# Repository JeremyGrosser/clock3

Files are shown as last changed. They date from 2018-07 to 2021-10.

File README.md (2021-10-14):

This repository contains firmware for my 3 time zone clock based on the [Adafruit Feather M0 Wifi](https://www.adafruit.com/product/3010). This project is very incomplete and is unlikely to be reproducible with the code listed here.

Some of the software components (eg. samd21 drivers) may be useful to others, so I'm making this repository public, but have no intention to maintain it long term.

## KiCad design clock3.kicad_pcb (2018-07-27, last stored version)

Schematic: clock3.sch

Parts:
BAT1: BS-7; Battery_Holder_Coin_2032_BS-7; MPN BS-7; Digi-Key_PN BS-7-ND
BOOT1, BOOT2: EG1218; Switch_Slide_11.6x4mm_EG1218; MPN EG1218; Digi-Key_PN EG1903-ND
C1, C2, C9: 4.7uF; C_0603_1608Metric
C3: 10uF; C_0805_2012Metric
C4, C5: 16pF; C_0603_1608Metric
C6, C7, C8, C12, C13, C14, C15: 100nF; C_0603_1608Metric
C10: 10nF; C_0603_1608Metric
C11: 1uF; C_0603_1608Metric
C17, C18: 5pF; C_0603_1608Metric
D1, D2, D3, D4: LED; LED_1206_3216Metric
J1: 10118194-0001LF; USB_Micro_B_Female_10118194-0001LF; MPN 10118194-0001LF; Digi-Key_PN 609-4618-1-ND
J2: SWD; Molex_KK-254_AE-6410-06A_1x06_P2.54mm_Vertical
J3, J4, J5: Conn_01x06_Male; Molex_KK-254_AE-6410-06A_1x06_P2.54mm_Vertical
MK1, MK2, MK3, MK4: Mounting_Hole_PAD; MountingHole_2.2mm_M2_DIN965_Pad
R2, R3: 10k; R_0603_1608Metric
R4, R5, R6, R7: R; R_0603_1608Metric
S1, S2, S3, S4: B3F-3150
U1: AP2114H-3_3TRG1; SOT-223; MPN AP2114H-3.3TRG1; Digi-Key_PN AP2114H-3.3TRG1DICT-ND
U2: STM32F102CBTx; LQFP-48_7x7mm_P0.5mm
Y1: 8MHz 18pF 30ppm; Crystal_SMD_HC49-US_AT49
Y2: 32.768kHz 12.5pF 20ppm; Crystal_SMD_SeikoEpson_MC146-4Pin_6.7x1.5mm

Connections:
/BOOT0: R2.2, U2.44 (BOOT0)
/BOOT1: R3.2, U2.20 (PB2)
/BUTTON1: C12.2, S1.1, U2.28 (PB15)
/BUTTON2: C13.2, S2.1, U2.27 (PB14)
/BUTTON3: C14.2, S3.1, U2.26 (PB13)
/I2C1_SCL: J3.4, J4.4, J5.4, U2.42 (PB6)
/I2C1_SDA: J3.3, J4.3, J5.3, U2.43 (PB7)
/LED1: D1.1, U2.10 (PA0)
/LED2: D2.1, U2.11 (PA1)
/LED3: D3.1, U2.29 (PA8)
/SWCLK: J2.2, U2.37 (PA14)
/SWDIO: J2.4, U2.34 (PA13)
/SWO: J2.6, U2.39 (PB3)
/USB_D+: J1.3, U2.33 (PA12)
/USB_D-: J1.2, U2.32 (PA11)
/VBAT: BAT1.Pos, U2.1 (VBAT)
/~RESET: C15.2, J2.5, S4.1, U2.7 (NRST)
GND: BAT1.Neg, BOOT1.3, BOOT2.3, C1.2, C2.2, C3.2, C4.2, C5.2, C6.2, C7.2, C8.2, C9.2, C10.2, C11.2, C12.1, C13.1, C14.1, C15.1, C17.2, C18.2, J1.4, J1.5, J1.SH, J2.3, J3.2, J3.6, J4.2, J4.6, J5.2, J5.6, MK1.1, MK2.1, MK3.1, MK4.1, S1.2, S1.3, S1.4, S2.2, S2.3, S2.4, S3.2, S3.3, S3.4, S4.2, S4.3, S4.4, U1.1, U2.8 (VSSA), U2.23 (VSS), U2.35 (VSS), U2.47 (VSS)
unnamed: BOOT1.2, R2.1
unnamed: BOOT2.2, R3.1
unnamed: C4.1, U2.5 (PD0), Y1.2
unnamed: C5.1, U2.6 (PD1), Y1.1
unnamed: C17.1, U2.3 (PC14), Y2.2
unnamed: C18.1, U2.4 (PC15), Y2.1
unnamed: D1.2, R4.2
unnamed: D2.2, R5.2
unnamed: D3.2, R6.2
unnamed: D4.2, R7.2
VCC: C1.1, J1.1, J3.1, J4.1, J5.1, U1.3
VDD: BOOT1.1, BOOT2.1, C2.1, C3.1, C6.1, C7.1, C8.1, C9.1, C10.1, C11.1, J2.1, J3.5, J4.5, J5.5, R4.1, R5.1, R6.1, R7.1, U1.2, U1.4, U2.9 (VDDA), U2.24 (VDD), U2.36 (VDD), U2.48 (VDD)

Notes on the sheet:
POWER 5V IN 3.3V @ 1A OUT
DEBUG
LED DISPLAYS
USB
BUTTONS AND SWITCHES
WIFI
LEDS
VDD3
VDDA

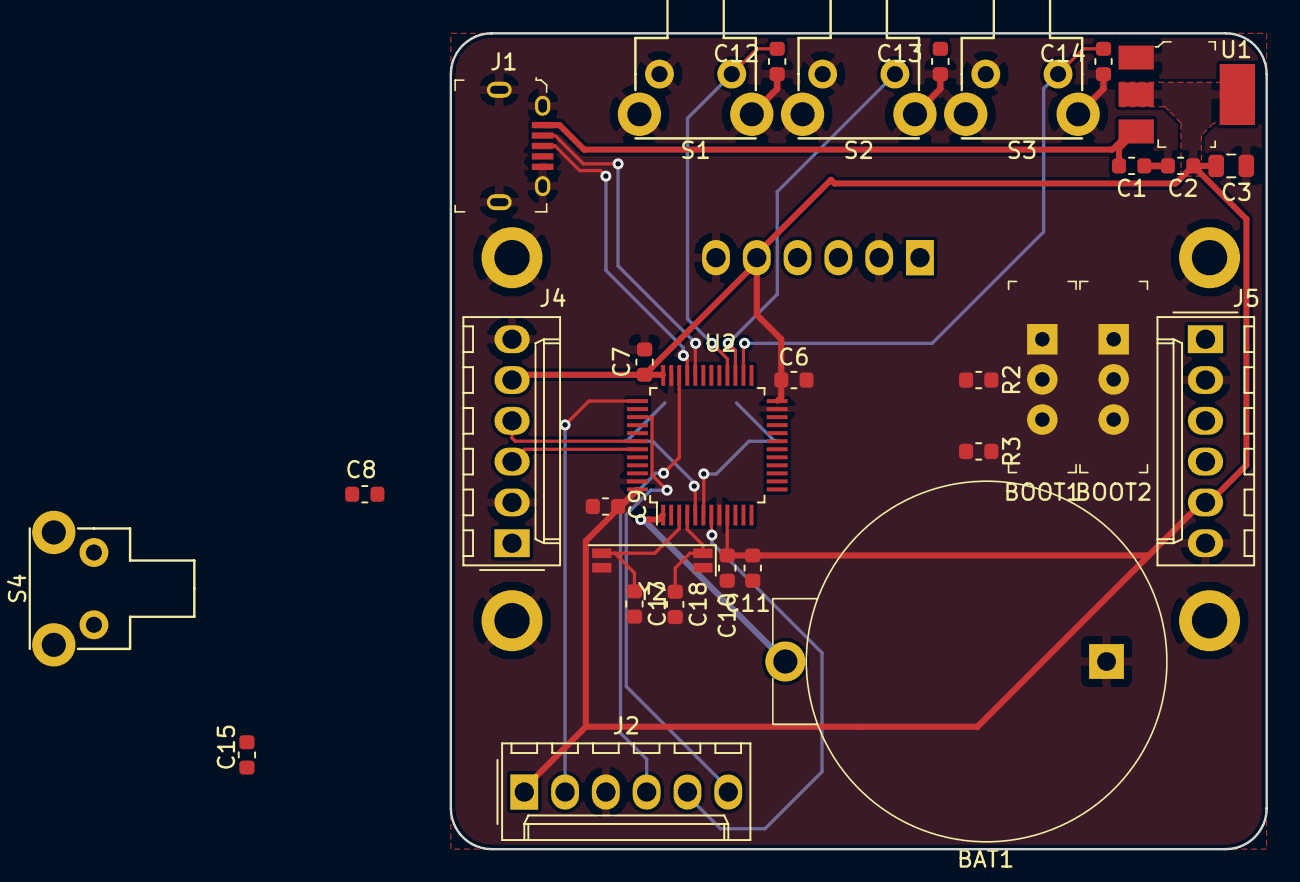
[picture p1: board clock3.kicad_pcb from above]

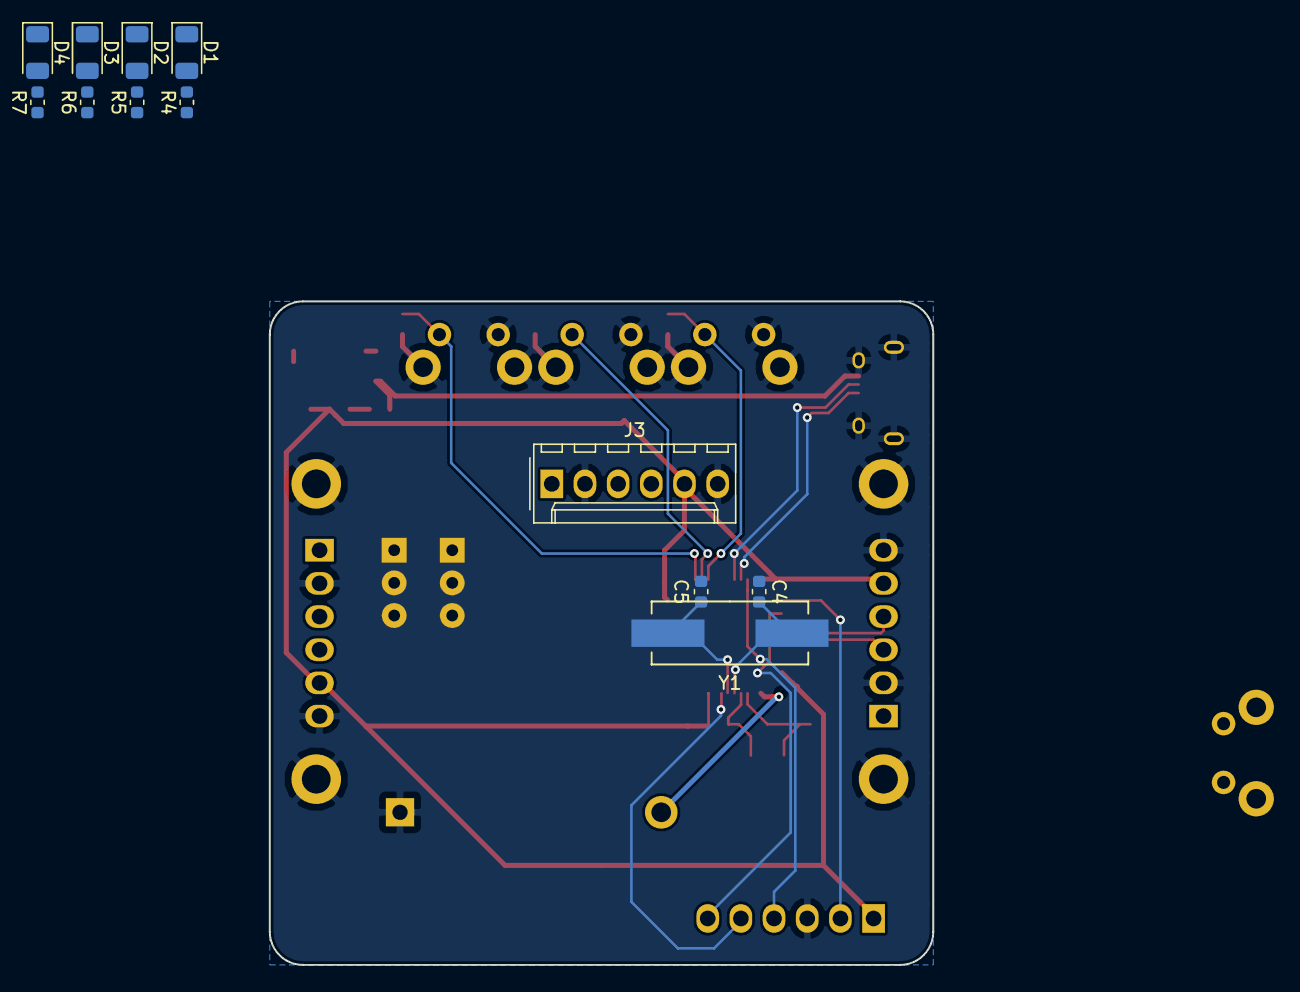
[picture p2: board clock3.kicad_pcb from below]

Board: 2 copper layers, 50.8 x 50.8 mm, 47 parts (12 on the bottom side), 30 nets.

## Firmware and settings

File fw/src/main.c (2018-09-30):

#include <platform/gpio.h>
#include <platform/i2c.h>
#include <platform/rtc.h>
#include <platform.h>
#include <board.h>

#include <stdint.h>
#include <stdio.h>
#include <string.h>

#include <sys/time.h>
#include <errno.h>

#include <driver/ht16k33/ht16k33.h>
#include <driver/atw/atw.h>

#define WIFI_SSID "sierra24"
#define WIFI_PSK "whatevenisapassword"

#define CONSOLE_MAXLEN 128
uint8_t console_buf[CONSOLE_MAXLEN] = {0};
uint8_t *console_ptr = console_buf;
size_t console_avail = CONSOLE_MAXLEN;

void process_command(uint8_t *line, size_t len) {
	printf("command[%d]: %s\r\n", len, line);
}

static void console_loop(void) {
	uint8_t *eol;
	int err;

	err = console_read(console_ptr, console_avail);
	if(err <= 0) {
		return;
	}

	console_ptr += err;
	console_avail -= err;

	eol = (uint8_t *)memchr(console_buf, '\n', CONSOLE_MAXLEN);
	if(eol != NULL) {
		process_command(console_buf, (eol - console_buf));
		memset(console_buf, 0x00, CONSOLE_MAXLEN);
		console_ptr = console_buf;
		console_avail = CONSOLE_MAXLEN;
	}else if(console_avail == 0) {
		printf("console buffer overflow!\r\n\r\n");
		memset(console_buf, 0x00, CONSOLE_MAXLEN);
		console_ptr = console_buf;
		console_avail = CONSOLE_MAXLEN;
	}
}

void button0_interrupt(void) {
	struct tm *now;

	now = rtc_read();
	now->tm_min = ((now->tm_min + 1) % 60);
	now->tm_sec = 0;
	rtc_write(now);
}

void button1_interrupt(void) {
	struct tm *now;

	now = rtc_read();
	now->tm_hour = ((now->tm_hour + 1) % 24);
	rtc_write(now);
}

void display_time(ht16k33_t *display, struct tm *now) {
	if(now->tm_hour > 0) {
		ht16k33_set(display, ht16k33_column[0], ht16k33_digit[now->tm_hour / 10]);
		ht16k33_set(display, ht16k33_column[1], ht16k33_digit[now->tm_hour % 10]);
	}else{
		ht16k33_set(display, ht16k33_column[0], ht16k33_digit[0]);
		ht16k33_set(display, ht16k33_column[1], ht16k33_digit[0]);
	}

	if(now->tm_min > 0) {
		ht16k33_set(display, ht16k33_column[2], ht16k33_digit[now->tm_min / 10]);
		ht16k33_set(display, ht16k33_column[3], ht16k33_digit[now->tm_min % 10]);
	}else{
		ht16k33_set(display, ht16k33_column[2], ht16k33_digit[0]);
		ht16k33_set(display, ht16k33_column[3], ht16k33_digit[0]);
	}
	ht16k33_set(display, ht16k33_column[4], ht16k33_colon);

	ht16k33_flush(display);
}

int main(void) {
	ht16k33_t display[3];
	struct tm *now;
	time_t epoch;
	struct timeval tv;
	int err;

	err = board_init();
	if(err != 0) {
		printf("board_init err=%d\r\n", err);
	}

	/*
	err = atw_connect_wpa(&wifi, (uint8_t *)WIFI_SSID, strlen(WIFI_SSID), (uint8_t *)WIFI_PSK, strlen(WIFI_PSK));
	if(err != 0) {
		printf("atw_connect_wpa failed\r\n");
	}
	*/

	display[0].i2c = &DISPLAY_I2C;
	display[0].i2c_addr = 0x70;
	display[0].brightness = 8;

	display[1].i2c = &DISPLAY_I2C;
	display[1].i2c_addr = 0x73;
	display[1].brightness = 8;

	display[2].i2c = &DISPLAY_I2C;
	display[2].i2c_addr = 0x71;
	display[2].brightness = 8;

	err = ht16k33_setup(&display[0]);
	if(err != 0) {
		printf("display 0 setup failed\r\n");
	}
	err = ht16k33_setup(&display[1]);
	if(err != 0) {
		printf("display 1 setup failed\r\n");
	}
	err = ht16k33_setup(&display[2]);
	if(err != 0) {
		printf("display 2 setup failed\r\n");
	}

	gpio_write(&STATUS_LED, LED_OFF);

	while(1) {
		err = gettimeofday(&tv, NULL);
		if(err != 0) {
			printf("gettimeofday failed: %s\r\n", strerror(errno));
		}else{
			epoch = tv.tv_sec + (3600 * -7);
			now = gmtime(&epoch);
			display_time(&display[0], now);

			epoch = tv.tv_sec + (3600 * -4);
			now = gmtime(&epoch);
			display_time(&display[1], now);

			epoch = tv.tv_sec;
			now = gmtime(&epoch);
			display_time(&display[2], now);
		}

		//atw_handle_events(&wifi);
		console_loop();

		gpio_write(&STATUS_LED, LED_OFF);
		__WFI();
		gpio_write(&STATUS_LED, LED_ON);
	}

	return 0;
}

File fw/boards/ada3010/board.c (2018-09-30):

#include <board.h>
#include <platform.h>
#include <platform/gpio.h>
#include <platform/spi.h>
#include <platform/rtc.h>
#include <platform/i2c.h>
//#include <platform/uart.h>
//#include <driver/atw/atw.h>

#include <stdio.h>

void wifi_interrupt(void) {
	atw_interrupt(&wifi);
}

gpio_t STATUS_LED = {
	.num	= PIN_PA17,
	.config	= {
		.direction	= DIR_OUT,
		.drive		= DRIVE_HIGH,
		.pull		= PULL_ENABLE,
		.pmux		= PMUX_DISABLE,
	},
};

gpio_t BUTTON0 = {
	.num	= PIN_PA02,
	.config	= {
		.direction	= DIR_IN,
		.pull		= PULL_ENABLE,
		.pmux		= PMUX_ENABLE,
		.pmux_function = MUX_PA02A_EIC_EXTINT2,
	},
	.interrupt = {
		.num	= 2,
		.sense	= SENSE_RISE,
		.filter	= FILTER_ENABLE,
		.function = &button0_interrupt,
	},
};

gpio_t BUTTON1 = {
	.num	= PIN_PB08,
	.config	= {
		.direction	= DIR_IN,
		.pull		= PULL_ENABLE,
		.pmux		= PMUX_ENABLE,
		.pmux_function = MUX_PB08A_EIC_EXTINT8,
	},
	.interrupt = {
		.num	= 8,
		.sense	= SENSE_RISE,
		.filter	= FILTER_ENABLE,
		.function = &button1_interrupt,
	},
};

gpio_t ATW_CS = {
	.num	= PIN_PA06,
	.config	= {
		.direction	= DIR_OUT,
		.drive		= DRIVE_LOW,
		.pull		= PULL_ENABLE,
		.pmux		= PMUX_DISABLE,
	},
};

gpio_t ATW_RST = {
	.num	= PIN_PA08,
	.config	= {
		.direction	= DIR_OUT,
		.drive		= DRIVE_LOW,
		.pull		= PULL_ENABLE,
		.pmux		= PMUX_DISABLE,
	},
};

gpio_t ATW_IRQ = {
	.num	= PIN_PA21,
	.config	= {
		.direction		= DIR_IN,
		.drive			= DRIVE_LOW,
		.pull			= PULL_ENABLE,
		.pmux			= PMUX_ENABLE,
		.pmux_function	= MUX_PA21A_EIC_EXTINT5,
	},
	.interrupt = {
		.num	= 5,
		.sense	= SENSE_RISE,
		.filter	= FILTER_DISABLE,
		.function = &wifi_interrupt,
	},
};

gpio_t ATW_MOSI = {
	.num	= PIN_PB10,
	.config = {
		.direction		= DIR_OUT,
		.drive			= DRIVE_LOW,
		.pull			= PULL_ENABLE,
		.pmux			= PMUX_ENABLE,
		.pmux_function	= MUX_PB10D_SERCOM4_PAD2,
	},
};

gpio_t ATW_MISO = {
	.num	= PIN_PA12,
	.config = {
		.direction		= DIR_IN,
		.drive			= DRIVE_LOW,
		.pull			= PULL_DISABLE,
		.pmux			= PMUX_ENABLE,
		.pmux_function	= MUX_PA12D_SERCOM4_PAD0,
	},
};

gpio_t ATW_SCK = {
	.num	= PIN_PB11,
	.config = {
		.direction		= DIR_OUT,
		.drive			= DRIVE_LOW,
		.pull			= PULL_DISABLE,
		.pmux			= PMUX_ENABLE,
		.pmux_function	= MUX_PB11D_SERCOM4_PAD3,
	},
};

gpio_t ATW_CHIP_EN = {
	.num	= PIN_PA14,
	.config = {
		.direction		= DIR_OUT,
		.drive			= DRIVE_HIGH,
		.pull			= PULL_ENABLE,
		.pmux			= PMUX_DISABLE,
	},
};

/*
gpio_t CONSOLE_TXD = {
	.num	= PIN_PA10,
	.config = {
		.direction		= DIR_OUT,
		.drive			= DRIVE_HIGH,
		.pull			= PULL_ENABLE,
		.pmux			= PMUX_ENABLE,
		.pmux_function	= MUX_PA10C_SERCOM0_PAD2,
	},
};

gpio_t CONSOLE_RXD = {
	.num	= PIN_PA11,
	.config = {
		.direction		= DIR_IN,
		.drive			= DRIVE_HIGH,
		.pull			= PULL_ENABLE,
		.pmux			= PMUX_ENABLE,
		.pmux_function	= MUX_PA11C_SERCOM0_PAD3,
	},
};

uart_t CONSOLE_UART = {
	.num	= 0,
	.sercom = &SERCOM0->USART,
	.txd	= &CONSOLE_TXD,
	.rxd	= &CONSOLE_RXD,
	.tx_pad = 2,
	.rx_pad	= 3,
};
*/

gpio_t I2C_SDA = {
	.num	= PIN_PA22,
	.config	= {
		.direction	= DIR_OUT,
		.drive		= DRIVE_LOW,
		.pull		= PULL_ENABLE,
		.pmux		= PMUX_ENABLE,
		.pmux_function = MUX_PA22C_SERCOM3_PAD0,
	},
};

gpio_t I2C_SCL = {
	.num	= PIN_PA23,
	.config	= {
		.direction	= DIR_OUT,
		.drive		= DRIVE_LOW,
		.pull		= PULL_ENABLE,
		.pmux		= PMUX_ENABLE,
		.pmux_function = MUX_PA23C_SERCOM3_PAD1,
	},
};

i2c_t DISPLAY_I2C = {
	.num = 3,
	.scl = &I2C_SCL,
	.sda = &I2C_SDA,
};

int board_init() {
	spi_t spi;
	int err;

	platform_init();

	gpio_setup(&STATUS_LED);
	gpio_write(&STATUS_LED, LED_ON);

	/*
	err = uart_init(&CONSOLE_UART);
	if(err != 0) {
		return err;
	}
	*/
	printf("\033[2J\033[0;0H");
	printf("\r\n\r\nada3010 board_init\r\n");

	rtc_init();
	i2c_init(&DISPLAY_I2C);

	gpio_setup(&BUTTON0);
	gpio_setup(&BUTTON1);
	gpio_write(&BUTTON0, 0);
	gpio_write(&BUTTON1, 0);

	spi.num		= 4;
	spi.mosi	= &ATW_MOSI;
	spi.miso	= &ATW_MISO;
	spi.sck		= &ATW_SCK;
	spi.nss		= &ATW_CS;
	spi.miso_pad = 0;
	spi.mosi_pad = 2;
	spi.sck_pad	= 3;

	err = spi_setup(&spi);
	if(err != 0) {
		return err;
	}

	gpio_setup(&ATW_CHIP_EN);
	gpio_write(&ATW_CHIP_EN, 0);

	wifi.spi			= &spi;
	wifi.gpio_rst		= &ATW_RST;
	wifi.gpio_irq		= &ATW_IRQ;
	wifi.gpio_chip_en	= &ATW_CHIP_EN;

	/*
	err = atw_setup(&wifi);
	if(err != 0) {
		return err;
	}
	*/

	return 0;
}

void console_write(uint8_t *msg, size_t len) {
	//uart_write(&CONSOLE_UART, msg, len);
}

int console_read(uint8_t *msg, size_t maxlen) {
	//return uart_read(&CONSOLE_UART, msg, maxlen);
	return -1;
}

void SERCOM4_Handler() {
	spi_interrupt(wifi.spi);
}

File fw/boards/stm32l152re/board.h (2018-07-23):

#ifndef STM32L152RE_BOARD_H
#define STM32L152RE_BOARD_H

#include <stm32l1xx.h>
#include <cmsis_gcc.h>
#include <stm32l1xx_hal.h>

#define GPIO_PORT_LED2	GPIOA
#define GPIO_PIN_LED2	GPIO_PIN_5

#define GPIO_PORT_I2C1		GPIOB
#define GPIO_PIN_I2C1_SCL	GPIO_PIN_8
#define GPIO_PIN_I2C1_SDA	GPIO_PIN_9

#define GPIO_PORT_OLED_RESET	GPIOA
#define GPIO_PIN_OLED_RESET		GPIO_PIN_15

#endif

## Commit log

2018-07-23 Routing complete
    [clock3-B.Cu.gbl, clock3-B.Mask.gbs, clock3-B.SilkS.gbo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]
2018-07-24 Refactor into multiple boards, gpio support
2018-07-25 Working blocking uart
2018-07-26 Now with rtc and power saving
2018-07-26 winc1500 driver
2018-07-27 i2c wip
2018-07-28 Loopy LEDs!
2018-08-03 Nuke unused driver code
2018-08-03 SPI clocks but no data moves
2018-08-04 No interrupts from driver or device
2018-08-05 Integrate I2C display on feather proto
2018-08-05 Add needed winc driver code
2018-08-05 Move driver headers into driver dirs
2018-08-05 ht16k33 dimming, disable atw driver, disable lto
2018-08-07 Less uart, more speed
2018-09-30 Pull in atw driver
2018-10-10 Clean slate for hardware
    [clock3-B.Cu.gbl, clock3-B.Mask.gbs, clock3-B.SilkS.gbo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]
2021-10-14 Add a link to the feather board in README
